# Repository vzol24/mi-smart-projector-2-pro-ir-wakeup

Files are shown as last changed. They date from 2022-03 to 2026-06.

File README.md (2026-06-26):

# Mi Smart Projector 2 Pro — IR Sleep / Wake

> Put a Xiaomi Mi Smart Projector 2 Pro to sleep and wake it back up with **any infrared remote**, using a tiny Arduino-based IR-to-USB bridge.

<p align="center">
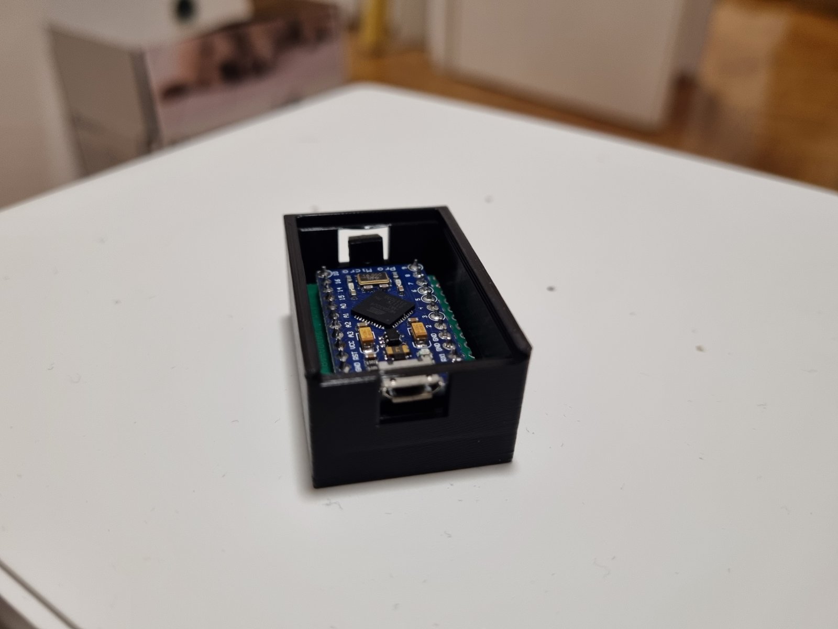
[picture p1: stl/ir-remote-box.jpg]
3D printed IR receiver box
  
</p>

---

🇬🇧 **English** · [🇭🇺 Magyar](#magyar)

## The problem

The Xiaomi Mi Smart Projector 2 Pro has no convenient "remote power on". This project adds one. A small box plugs into the projector's USB port and pretends to be a **USB keyboard**. It listens for two buttons on an infrared remote and translates them into USB key events the projector understands:

| Remote button | USB event sent | Result on projector |
|---|---|---|
| **Sleep** | `System Sleep` | Goes to standby |
| **Wake** | `Enter` key press | Wakes from standby  |

Because it decodes the **NEC** protocol, it works with a Broadlink RM, a spare LG TV remote, or any cheap NEC remote — you just teach it the two button codes.

## How it works

```
 IR remote  ──(infrared)──▶  IR receiver ──▶  Arduino Pro Micro ──(USB HID)──▶  Projector
```

1. The IR receiver picks up the remote's NEC signal.
2. The Arduino Pro Micro (ATmega32U4, native USB) decodes the command code.
3. Matching a known code, it emulates a USB keyboard and sends either a **System Sleep** power event or an **Enter** key press.

## Bill of materials

- **Arduino Pro Micro** (ATmega32U4) — native USB is required for HID emulation
- **IR receiver module** (e.g. TSOP38238 or VS1838B)
- A few jumper wires / a bit of soldering
- A **3D printer** for the enclosure (STL files included in [`/stl`](/stl))

## Wiring

| IR receiver pin | Arduino Pro Micro |
|---|---|
| VCC | VCC (5V) |
| GND | GND |
| OUT / DATA | `IR_RECEIVE_PIN`  |

The default `IR_RECEIVE_PIN` for the Pro Micro is defined in `PinDefinitionsAndMore.h` (pin `2`).

## Build & flash

1. Install the **Arduino IDE** and add Pro Micro / SparkFun AVR board support.
2. Install these libraries from the Library Manager:
   - **IRremote** by Armin Joachimsmeyer (v4.x or newer)
   - **HID-Project** by NicoHood
3. Open [`arduino/mi-smart-2-pro-ir/mi-smart-2-pro-ir.ino`](arduino/mi-smart-2-pro-ir/mi-smart-2-pro-ir.ino).
4. Select **SparkFun Pro Micro / ATmega32U4 (5V, 16 MHz)** as the board and upload.

## Teaching it your remote

The two button codes are configurable at the top of the sketch:

```cpp
constexpr uint8_t CMD_SLEEP = 177;  // button that puts the projector to sleep
constexpr uint8_t CMD_WAKE  = 176;  // button that wakes the projector up
```

To find the codes for *your* remote:

1. Open the **Serial Monitor** at `115200` baud.
2. Press a button — the decoded `command` value is printed.
3. Copy those values into `CMD_SLEEP` and `CMD_WAKE`, then re-upload.

## Enclosure

Print and assemble the box from the STL files in [`/stl`](/stl):

- [`box.stl`](stl/box.stl) — main body
- [`box-lid.stl`](stl/box-lid.stl) — lid

## License

Released under the [MIT License](LICENSE).

---

## Magyar

[🇬🇧 English](#mi-smart-projector-2-pro--ir-sleep--wake) · 🇭🇺 **Magyar**

> Altasd el és ébreszd fel a Xiaomi Mi Smart Projector 2 Pro projektort **bármilyen infravörös távirányítóval**, egy apró Arduino-alapú IR→USB híd segítségével.

### A probléma

A Xiaomi Mi Smart Projector 2 Pro nem rendelkezik kényelmes „távoli bekapcsolás” funkcióval. Ez a projekt pótolja ezt. Egy kis doboz csatlakozik a projektor USB portjára, és **USB billentyűzetnek** adja ki magát. Egy infravörös távirányító két gombját figyeli, és olyan USB eseményekké fordítja, amelyeket a projektor megért:

| Távirányító gomb | Küldött USB esemény | Hatás a projektoron |
|---|---|---|
| **Altatás** | `System Sleep` | Készenlétbe megy |
| **Ébresztés** | `Enter` lenyomás | Felébred készenlétből |

Mivel a **NEC** protokollt dekódolja, működik Broadlink RM-mel, egy felesleges LG TV távirányítóval, vagy bármilyen olcsó NEC távirányítóval — csak meg kell tanítani neki a két gombkódot.

### Hogyan működik

```
 IR távirányító ──(infra)──▶ IR vevő ──▶ Arduino Pro Micro ──(USB HID)──▶ Projektor
```

1. Az IR vevő veszi a távirányító NEC jelét.
2. Az Arduino Pro Micro (ATmega32U4, natív USB) dekódolja a parancskódot.
3. Ismert kód esetén USB billentyűzetet emulál, és vagy egy **System Sleep** energiagazdálkodási eseményt, vagy egy **Enter** billentyűt küld.

### Alkatrészek

- **Arduino Pro Micro** (ATmega32U4) — a HID emulációhoz natív USB szükséges
- **IR vevő modul** (pl. TSOP38238 vagy VS1838B)
- Néhány jumper vezeték / kevés forrasztás
- **3D nyomtató** a dobozhoz (az STL fájlok a [`/stl`](/stl) mappában)

### Bekötés

| IR vevő láb | Arduino Pro Micro |
|---|---|
| VCC | VCC (5V) |
| GND | GND |
| OUT / DATA  | `IR_RECEIVE_PIN`  |

A Pro Micro alapértelmezett `IR_RECEIVE_PIN` lába a `PinDefinitionsAndMore.h` fájlban van megadva (`2`-es láb).

### Fordítás és feltöltés

1. Telepítsd az **Arduino IDE**-t, és add hozzá a Pro Micro / SparkFun AVR board támogatást.
2. Telepítsd ezeket a könyvtárakat a Library Managerből:
   - **IRremote** — Armin Joachimsmeyer (v4.x vagy újabb)
   - **HID-Project** — NicoHood
3. Nyisd meg a [`arduino/mi-smart-2-pro-ir/mi-smart-2-pro-ir.ino`](arduino/mi-smart-2-pro-ir/mi-smart-2-pro-ir.ino) fájlt.
4. Válaszd ki a **SparkFun Pro Micro / ATmega32U4 (5V, 16 MHz)** boardot, és töltsd fel.

### A saját távirányítód betanítása

A két gombkód a forráskód tetején állítható:

```cpp
constexpr uint8_t CMD_SLEEP = 177;  // a projektort altató gomb
constexpr uint8_t CMD_WAKE  = 176;  // a projektort ébresztő gomb
```

A *saját* távirányítód kódjainak megtalálása:

1. Nyisd meg a **Serial Monitort** `115200` baud sebességen.
2. Nyomj meg egy gombot — a dekódolt `command` érték kiíródik.
3. Másold be ezeket az értékeket a `CMD_SLEEP` és `CMD_WAKE` konstansokba, majd töltsd fel újra.

### A doboz

Nyomtasd ki és szereld össze a dobozt a [`/stl`](/stl) mappa STL fájljaiból:

- [`box.stl`](stl/box.stl) — fő test
- [`box-lid.stl`](stl/box-lid.stl) — fedél

### Licenc

[MIT licenc](LICENSE) alatt kiadva.

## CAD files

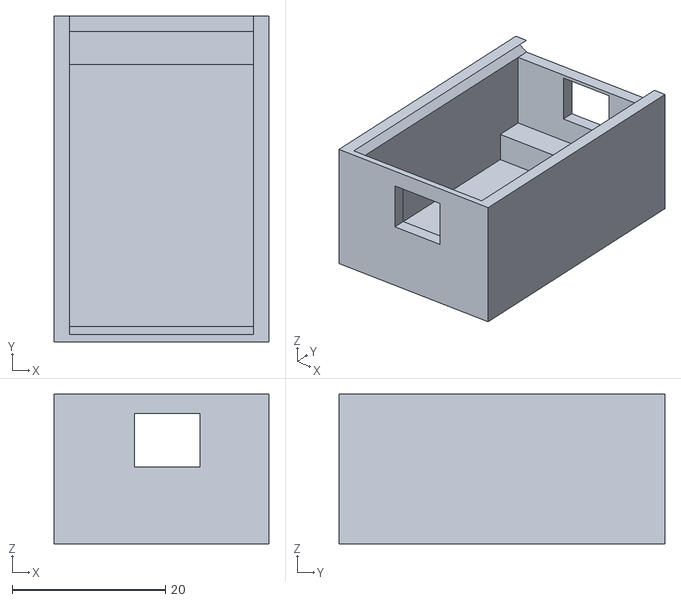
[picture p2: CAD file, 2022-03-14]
stl/box.stl
28.0 x 42.5 x 19.5

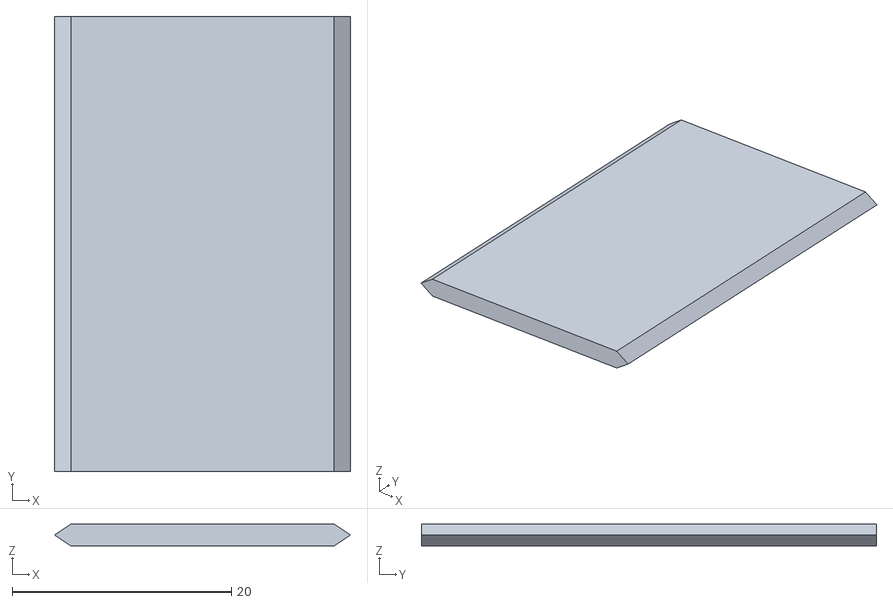
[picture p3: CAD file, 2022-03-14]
stl/box-lid.stl
27.0 x 41.5 x 2.00

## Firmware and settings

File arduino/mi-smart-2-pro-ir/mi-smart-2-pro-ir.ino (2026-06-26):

/*
 * mi-smart-2-pro-ir.ino
 *
 * IR-to-USB bridge for the Xiaomi Mi Smart Projector 2 Pro.
 *
 * The projector has no real "remote power on" feature, but it does react to
 * standard USB HID input. This sketch turns an Arduino Pro Micro (ATmega32U4)
 * into a tiny USB keyboard that listens for two infrared button presses:
 *
 *   - SLEEP button  -> sends the USB "System Sleep" event  -> projector sleeps
 *   - WAKE  button  -> sends the ENTER key                 -> projector wakes
 *
 * Any NEC-protocol IR remote works (e.g. a Broadlink RM, a spare LG TV remote,
 * or a cheap dedicated remote). Just read the command codes printed on the
 * serial monitor and plug them into the CMD_SLEEP / CMD_WAKE constants below.
 *
 * Hardware:
 *   - Arduino Pro Micro (ATmega32U4) -- native USB, required for HID
 *   - IR receiver (e.g. TSOP38238 / VS1838B) on IR_RECEIVE_PIN
 *
 * Libraries (install via the Arduino Library Manager):
 *   - IRremote  by Armin Joachimsmeyer  (>= 4.x)
 *   - HID-Project by NicoHood
 *
 * Author: vzol24
 * License: MIT
 */

/*
 * Only enable the NEC decoder. Limiting the active protocols keeps the build
 * smaller and decoding faster. NEC also covers Apple and Onkyo remotes.
 */
#define DECODE_NEC

#include <Arduino.h>
#include "HID-Project.h"

// Provides IR_RECEIVE_PIN and other per-board pin defaults.
#include "PinDefinitionsAndMore.h"

#include <IRremote.hpp>

// ---------------------------------------------------------------------------
// Configuration
// ---------------------------------------------------------------------------

// IR command codes for the two buttons. Read these off the serial monitor
// (115200 baud) while pressing the buttons on your own remote, then update them.
constexpr uint8_t CMD_SLEEP = 177;  // button that puts the projector to sleep
constexpr uint8_t CMD_WAKE  = 176;  // button that wakes the projector up

// Time to wait after acting on a command, to avoid a single long press or the
// remote's NEC repeat frames triggering the action multiple times (debounce).
constexpr unsigned long ACTION_COOLDOWN_MS = 2000;

// Short settle delay between starting an HID device and ending it.
constexpr unsigned long HID_SETTLE_MS = 300;

// ---------------------------------------------------------------------------
// Actions
// ---------------------------------------------------------------------------

// Send the USB "System Sleep" power event. The projector treats this like
// pressing its own power/standby button.
void sendSleep() {
    Serial.println(F("-> SLEEP"));
    System.begin();
    System.write(SYSTEM_SLEEP);
    delay(HID_SETTLE_MS);
    System.end();
}

// Send an ENTER key press to wake the projector from sleep.
void sendWake() {
    Serial.println(F("-> WAKE"));
    Keyboard.begin();
    Keyboard.write(KEY_ENTER);
    delay(HID_SETTLE_MS);
    Keyboard.end();
}

// ---------------------------------------------------------------------------
// Setup / Loop
// ---------------------------------------------------------------------------

void setup() {
    Serial.begin(115200);
    // Give the host a moment to (re)enumerate the USB serial port.
    delay(2000);
    Serial.println(F("START " __FILE__ " from " __DATE__
                     "\r\nUsing IRremote library version " VERSION_IRREMOTE));

    // Start the IR receiver; ENABLE_LED_FEEDBACK blinks the built-in LED on RX.
    IrReceiver.begin(IR_RECEIVE_PIN, ENABLE_LED_FEEDBACK);

    Serial.print(F("Ready to receive IR signals of protocols: "));
    printActiveIRProtocols(&Serial);
    Serial.print(F("at pin "));
    Serial.println(IR_RECEIVE_PIN);
}

void loop() {
    // Nothing to do until a full IR frame has been decoded.
    if (!IrReceiver.decode()) {
        return;
    }

    // Print a one-line summary of what was received. Handy for discovering the
    // command codes of a new remote, and for debugging in general.
    IrReceiver.printIRResultShort(&Serial);
    if (IrReceiver.decodedIRData.protocol == UNKNOWN) {
        // Unknown protocol: dump the raw timing so it can be analysed.
        IrReceiver.printIRResultRawFormatted(&Serial, true);
    }

    // Ignore NEC auto-repeat frames so holding a button does not fire repeatedly.
    const bool isRepeat = IrReceiver.decodedIRData.flags & IRDATA_FLAGS_IS_REPEAT;
    const uint8_t command = IrReceiver.decodedIRData.command;

    if (!isRepeat) {
        if (command == CMD_SLEEP) {
            sendSleep();
            delay(ACTION_COOLDOWN_MS);
        } else if (command == CMD_WAKE) {
            sendWake();
            delay(ACTION_COOLDOWN_MS);
        }
    }

    // Re-enable the receiver for the next frame. Receiving is paused after each
    // decoded packet, so this call is required.
    IrReceiver.resume();
}

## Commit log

2022-03-14 init stl
    [box-lid.stl, box.stl]
2026-06-26 Modernize firmware and docs
    - Rewrite the sketch with named config constants, helper functions,
    NEC repeat-frame filtering and thorough comments
    - Add a professional bilingual (EN/HU) README with wiring, build,
    flashing and remote-teaching instructions
    - Add MIT LICENSE
